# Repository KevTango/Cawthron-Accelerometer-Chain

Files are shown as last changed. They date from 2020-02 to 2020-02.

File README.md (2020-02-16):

# Cawthron Accelerometer Chain

## Author: Kevin Tang

### I wrote this code for Cawthron Institute during my internship, it is to measure the acceleration at 10 different points of the mussel farm rope and to log the data on a single SD card.

The file has three folders: 

* `receiver` for the receiver component measuring the acceleration and the temperature
* `datalogger` for requesting the data from the receiver and to log them on the SD card
* `PCB` containing the PCB files

## Code Setup

* `git clone` or download the code as a zip file

* Download uPycraft IDE or simply use a text editor such as Notepad++

* Copy respective files (main.py + boot.py + libraries) to SD card

**NOTE: If the SD card is larger than 32GB, use GUIFormat to format SD card to FAT32**

### Datalogger

1. Choose datalogging mode in `MODE` to `MODE = DATA_RATE_1HZ` for 1 Hz or `MODE = DATA_RATE_2HZ` for 2 Hz

2. To set up RTC, uncomment section under date initialisation and follow formatting

3. Run the code to save the time

4. Comment out the RTC code section as before to stop it from re-initialising the time each time

5. Rerun the code

* The red LED will light up to signify receiver 0 and/or 1 information has been received

* The green LED will light up to signify receiver 2 and/or 3 and/or 4 information has been received

* The yellow LED will light up to signify receiver 5 and/or 6 and/or 7 information has been received

* The blue LED will light up to signify receiver 8 and/or 9 information has been received

### Receiver

1. Configure ID from 0-9 under `ID = _` **MAKE SURE EACH ID NUMBER IS DIFFERENT**

2. To set up RTC, uncomment section under date initialisation and follow formatting

3. Run the code to save the time

4. Comment out the RTC code section as before to stop it from re-initialising the time each time

5. Rerun the code

* The Green LED will flash to signify the receiver has transmitted to the datalogger 

## PCB

Components needed and links for 1 datalogger and 10 receivers:

* [11 x Pyboard](https://www.digikey.co.nz/products/en?mpart=DEV-14412&v=1568)

* [11 x 1N4148](https://nz.element14.com/diodes-inc/1n4148w-7-f/diode-switch-300ma-100v-sod123/dp/1776392?st=1N4148W-7-F)

* [11 x 47uF Electrolytic Capacitor](https://nz.element14.com/panasonic/eee1ca470sp/ae-capacitor-case-radial-can-smd/dp/9696946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)

* [11 x 100nF Capacitor](https://nz.element14.com/avx/08055c104jat2a/cap-0-1-f-50v-5-x7r-0805/dp/1740673?st=100nF%200805)

* [11 x DS3231M](https://www.digikey.co.nz/product-detail/en/maxim-integrated/DS3231MPMB1/DS3231MPMB1-ND/3661364)

* [11 x CR1025 Batteries](https://www.mrpositive.co.nz/panasonic-cr1025-3v-lithium-button-cell-battery)

* [11 x TTL to RS485 Converter](https://www.aliexpress.com/item/32668863095.html)

* [10 x LIS3DH](https://www.adafruit.com/product/2809)

* [10 x TMP36](https://www.digikey.co.nz/product-detail/en/analog-devices-inc/TMP36GT9Z/TMP36GT9Z-ND/820404)

* M3 Standoffs (Optional)

Wiring diagram is provided in the PCB folder (datalogger_schematic.PNG and receiver_schematic.PNG)

Make sure the terminal A connect with other terminal A and same for terminal B

## Ordering PCBs 

I have provided the zip files containing gerber files and NC drill files in the PCB folder (Datalogger_v3.zip and Receiver_v3.zip)
[JLCPCB](https://jlcpcb.com/) is recommended

Datalogger board size: 74mm x 73mm

Receiver board size: 74mm x 70mm

## Troubleshooting

* Sometimes the compiler will append code at the bottom of original code, make sure to delete it

* If all the LEDs are flashing in order (e.g. board is corrupted), hold the USR button then the RST button.
Let go of the USR button and let go of the RST button once the yellow+green LEDs light up to reset board to factory settings.
Recopy code to SD card

* If there are errors in the code, make sure to copy the whole code, 
press Ctrl+E to enter copy paste mode in the REPL/console, paste the code then press Ctrl+D to run the code and view the error

* The csv file cannot be viewed while the SD card is plugged into the Pyboard. A SD card reader is required to view the csv file

* The watchdog timer has been disabled if the pyboard has been powered by a USB to ensure ease of debugging.
Make sure to power the Pyboard with a battery if in use.
Otherwise, enable the watchdog timers

**If there are any issues with the code/components email me or open up an issue on GitHub**

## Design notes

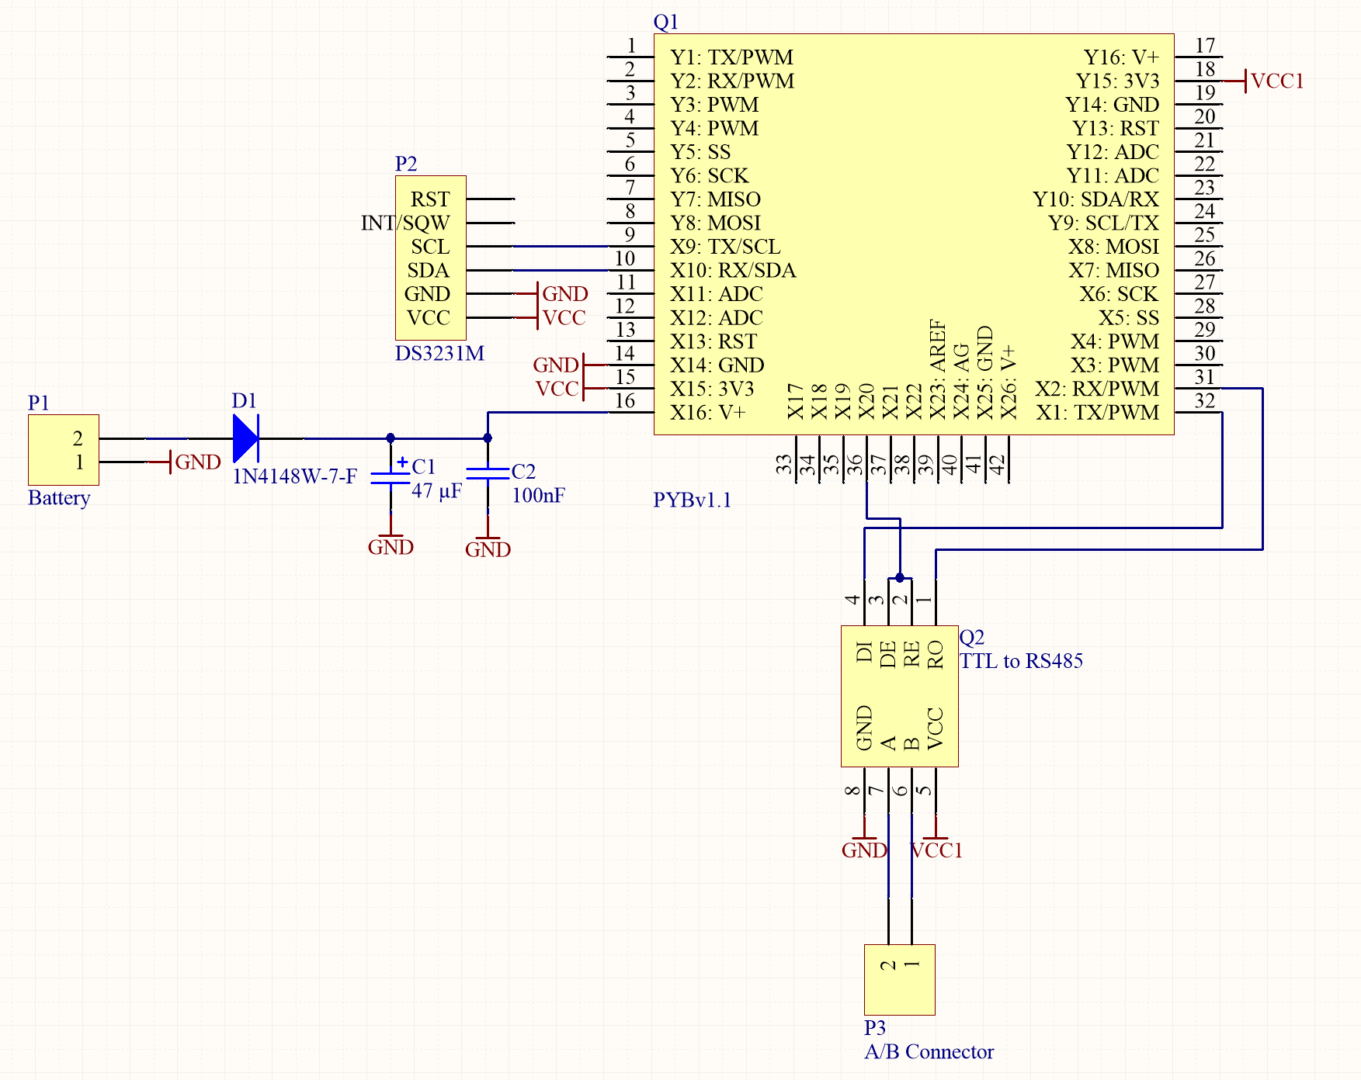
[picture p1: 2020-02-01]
PCB/Datalogger/datalogger_schematic.PNG

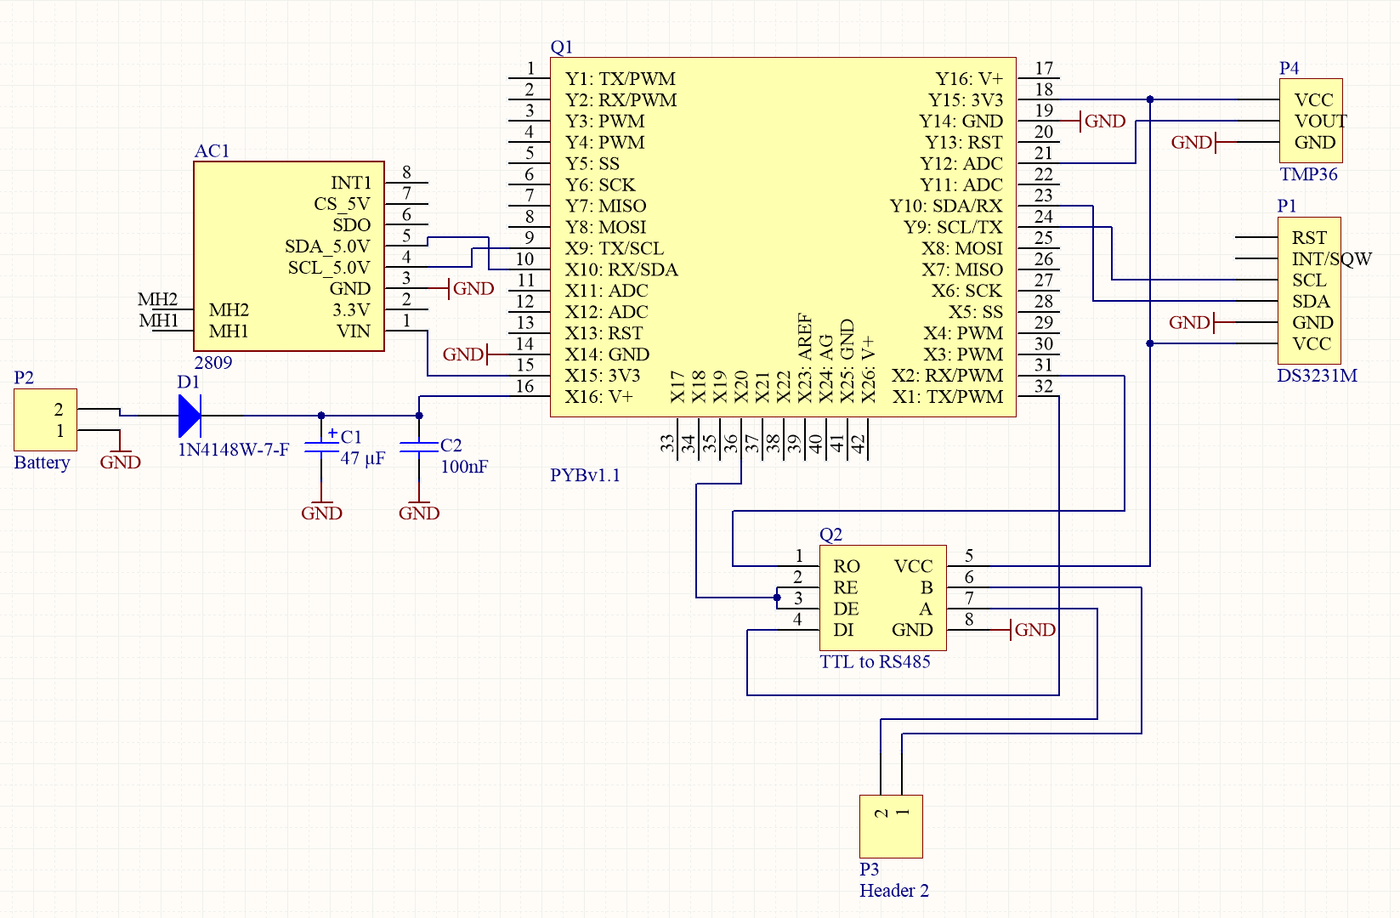
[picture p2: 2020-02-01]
PCB/Receiver/receiver_schematic.PNG

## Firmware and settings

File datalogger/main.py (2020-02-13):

# Datalogger code for Cawthron Institute's mussel farm accelerometer chain
# Author: Kevin Tang

"""
DEFAULT SETTINGS

MODE = DATA_RATE_1HZ
BAUD RATE: 9600
UART DATA FRAME: bits=8, parity=None, stop=1, timeout=1000
WDT TIMEOUT: 3000ms
1 HZ SLEEP: 30s
2 HZ SLEEP: 10s
"""

from machine import Pin, I2C, SPI, UART, WDT
from ds3231_port import DS3231
from pyb import RTC

import utime
import time
import sys
import os

# Timeout values
global SLEEP_1HZ
global SLEEP_2HZ

SLEEP_1HZ = 30
SLEEP_2HZ = 10

# Modes
global DATA_RATE_1HZ
global DATA_RATE_2HZ
global MODE

DATA_RATE_1HZ = 'one'
DATA_RATE_2HZ = 'two'

MODE = DATA_RATE_1HZ # Choose modes here (DATA_RATE_1HZ or DATA_RATE_2HZ)

# Enable Watchdog timer when batteries are plugged in.
global TIMEOUT_VALUE
TIMEOUT_VALUE = 3000

if pyb.Pin.board.USB_VBUS.value() == 0:
  wdt = WDT(timeout = TIMEOUT_VALUE) # enable watchdog timer

if sys.platform == 'pyboard':
  # Pin connections
  tx_enable = Pin('X20', mode=Pin.OUT)
  
  # RTC initialisation
  i2c = I2C(1) # Pins X9 and X10
  ds3231 = DS3231(i2c)
  
  # UART initialisation
  uart = UART(4, 115200) # Pins X1 and X2
  uart.init(115200, bits=8, parity=None, stop=1, timeout=1000) # Blocking UART of 1 second
  
else: 
  print('Incompatible system detected, please connect a pyboard')
  
# Date initialisation
rtc = RTC()
timeCheck = ds3231.get_time() # Gets current time

rtc.datetime((timeCheck[0], timeCheck[1], timeCheck[2], timeCheck[6], timeCheck[3], timeCheck[4], timeCheck[5], 0)) # Syncs RTC clock to local time

"""
# Sets up RTC, uncomment to manually set the clock (NOTE: DAY OF WEEK AND TIME ZONE IS NOT WORKING)
rtc.datetime((2020, 2, 11, 2, 16, 7, 40, 0))  # Comment out if already programmed
ds3231.save_time()

# RTC Format: YY, MM, DD, Day of week (Mon = 1), hh, mm, ss, time zone
# Example: 16/12/2019 @ Monday 16:13:00
# = rtc.datetime((2019, 12, 16, 1, 16, 13, 0, 0))
"""

# Checks to see if the csv file is empty, then writes the file if it is empty
for i in range(10):
  string = "/sd/accelerometer" + str(i) + ".csv"
  try:
    with open(string) as fileEmptyTest:
      emptyTest = fileEmptyTest.read(1)
      if not emptyTest:
        log_header = open(string, "a")
        log_header.write("ID, Date, Time, X Acceleration, Y Acceleration, Z Acceleration, Temperature \n")
        log_header.close() 
  except OSError: # File does not exist, make the files and headers
    log_header = open(string, "a")
    log_header.write("ID, Date, Time, X Acceleration, Y Acceleration, Z Acceleration, Temperature \n")
    log_header.close() 

# Retrieves date
def getDate():
  return str(rtc.datetime()[2]) + '/' + str(rtc.datetime()[1]) + '/' + str(rtc.datetime()[0])

# Retrieves time
def getTime():
  return str(rtc.datetime()[4]) + ':' + str(rtc.datetime()[5]) + ':' + str(rtc.datetime()[6])

# Sleep timer
def rest():
  if MODE == DATA_RATE_1HZ:
    for i in range(SLEEP_1HZ - 1):
      if(pyb.Pin.board.USB_VBUS.value() == 1):
        time.sleep(1)
      else:
        wdt.feed()
        rtc.wakeup(1000)
        pyb.stop()
        rtc.wakeup(None)
  else:
    for i in range(SLEEP_2HZ - 1):
      wdt.feed()
      if(pyb.Pin.board.USB_VBUS.value() == 1):
        time.sleep(1)
      else:
        wdt.feed()
        rtc.wakeup(1000)
        pyb.stop()
        rtc.wakeup(None)
  
# Reading UART value and converting to string
def uartProcess():
  test = uart.read()
  dataString = str(test)[2:-4]
  dataString = dataString.split('...')
  splitString = [i.split(',') for i in dataString]
  return splitString

# Sends mode information to receiver
def modeSelection():
  if MODE == DATA_RATE_1HZ:
    uart.write("uno")
  else:
    uart.write("dos")

# Remove WDT when USB is plugged in
def wdtCheck():
  if(pyb.Pin.board.USB_VBUS.value() == 0):
    wdt.feed()
   
# Checks if the last character is a digit and force reset if it isn't (garbage value check)
global lastChar

def charCheck():
  try:
    testing = [i for i in lastChar if i.isdigit()]
    if testing == []:
      print("Non digit detected. Forcing reset")
      wdt = WDT(timeout = 1) # Force watchdog timer
  except:
    print('Exception Error. Forcing reset')
    wdt = WDT(timeout = 1) # Force watchdog timer
  
# Resets receiver data buffers and respective sleep values based on mode selection on first start
tx_enable.value(1)
uart.write(MODE)
tx_enable.value(0)

while True:
  wdtCheck()
  print(getDate()) # Date
  print(getTime()) # Time
  
  # Print mode
  if MODE == DATA_RATE_1HZ:
    print("Mode: 1 Hz")
  else:
    print("Mode: 2 Hz")
  
  tx_enable.value(1)
  modeSelection()
  uart.write('0')
  tx_enable.value(0)
  splitString = uartProcess()
  if(splitString[0][0] == '0'):
    log_header0 = open("/sd/accelerometer0.csv", "a")
    for i in range(len(splitString)):
      log_header0.write(splitString[i][0] + ", " + splitString[i][1] + ", " + splitString[i][2] + ", " + splitString[i][3] + ", " \
      + splitString[i][4] + ", " + splitString[i][5] + ", " + splitString[i][6] + " \n")
    log_header0.close()
    print("Receiver 0 logged")
    pyb.LED(1).on()
    lastTemp = splitString[-1][-1]
    lastChar = list(lastTemp[-1])
    charCheck()
  
  wdtCheck()
  tx_enable.value(1)
  modeSelection()
  uart.write('1')
  tx_enable.value(0)
  splitString = uartProcess()
  if(splitString[0][0] == '1'):
    log_header1 = open("/sd/accelerometer1.csv", "a")
    for i in range(len(splitString)):
      log_header1.write(splitString[i][0] + ", " + splitString[i][1] + ", " + splitString[i][2] + ", " + splitString[i][3] + ", " \
      + splitString[i][4] + ", " + splitString[i][5] + ", " + splitString[i][6] + " \n")
    log_header1.close()
    print("Receiver 1 logged")
    pyb.LED(1).on()
    lastTemp = splitString[-1][-1]
    lastChar = list(lastTemp[-1])
    charCheck()
  
  wdtCheck()
  tx_enable.value(1)
  modeSelection()
  uart.write('2')
  tx_enable.value(0)
  splitString = uartProcess()
  if(splitString[0][0] == '2'):
    log_header2 = open("/sd/accelerometer2.csv", "a")
    for i in range(len(splitString)):
      log_header2.write(splitString[i][0] + ", " + splitString[i][1] + ", " + splitString[i][2] + ", " + splitString[i][3] + ", " \
      + splitString[i][4] + ", " + splitString[i][5] + ", " + splitString[i][6] + " \n")
    log_header2.close()
    print("Receiver 2 logged")
    pyb.LED(2).on()
    lastTemp = splitString[-1][-1]
    lastChar = list(lastTemp[-1])
    charCheck()
   
  wdtCheck() 
  tx_enable.value(1)
  modeSelection()
  uart.write('3')
  tx_enable.value(0)
  splitString = uartProcess()
  if(splitString[0][0] == '3'):
    log_header3 = open("/sd/accelerometer3.csv", "a")
    for i in range(len(splitString)):
      log_header3.write(splitString[i][0] + ", " + splitString[i][1] + ", " + splitString[i][2] + ", " + splitString[i][3] + ", " \
      + splitString[i][4] + ", " + splitString[i][5] + ", " + splitString[i][6] + " \n")
    log_header3.close()
    print("Receiver 3 logged")
    pyb.LED(2).on()
    lastTemp = splitString[-1][-1]
    lastChar = list(lastTemp[-1])
    charCheck()
   
  wdtCheck() 
  tx_enable.value(1)
  modeSelection()
  uart.write('4')
  tx_enable.value(0)
  splitString = uartProcess()
  if(splitString[0][0] == '4'):
    log_header4 = open("/sd/accelerometer4.csv", "a")
    for i in range(len(splitString)):
      log_header4.write(splitString[i][0] + ", " + splitString[i][1] + ", " + splitString[i][2] + ", " + splitString[i][3] + ", " \
      + splitString[i][4] + ", " + splitString[i][5] + ", " + splitString[i][6] + " \n")
    log_header4.close()
    print("Receiver 4 logged")
    pyb.LED(2).on()
    lastTemp = splitString[-1][-1]
    lastChar = list(lastTemp[-1])
    charCheck()
    
  wdtCheck()
  tx_enable.value(1)
  modeSelection()
  uart.write('5')
  tx_enable.value(0)
  splitString = uartProcess()
  if(splitString[0][0] == '5'):
    log_header5 = open("/sd/accelerometer5.csv", "a")
    for i in range(len(splitString)):
      log_header5.write(splitString[i][0] + ", " + splitString[i][1] + ", " + splitString[i][2] + ", " + splitString[i][3] + ", " \
      + splitString[i][4] + ", " + splitString[i][5] + ", " + splitString[i][6] + " \n")
    log_header5.close()
    print("Receiver 5 logged")
    pyb.LED(3).on()
    lastTemp = splitString[-1][-1]
    lastChar = list(lastTemp[-1])
    charCheck()
  
  wdtCheck()
  tx_enable.value(1)
  modeSelection()
  uart.write('6')
  tx_enable.value(0)
  splitString = uartProcess()
  if(splitString[0][0] == '6'):
    log_header6 = open("/sd/accelerometer6.csv", "a")
    for i in range(len(splitString)):
      log_header6.write(splitString[i][0] + ", " + splitString[i][1] + ", " + splitString[i][2] + ", " + splitString[i][3] + ", " \
      + splitString[i][4] + ", " + splitString[i][5] + ", " + splitString[i][6] + " \n")
    log_header6.close()
    print("Receiver 6 logged")
    pyb.LED(3).on()
    lastTemp = splitString[-1][-1]
    lastChar = list(lastTemp[-1])
    charCheck()
   
  wdtCheck() 
  tx_enable.value(1)
  modeSelection()
  uart.write('7')
  tx_enable.value(0)
  splitString = uartProcess()
  if(splitString[0][0] == '7'):
    log_header7 = open("/sd/accelerometer7.csv", "a")
    for i in range(len(splitString)):
      log_header7.write(splitString[i][0] + ", " + splitString[i][1] + ", " + splitString[i][2] + ", " + splitString[i][3] + ", " \
      + splitString[i][4] + ", " + splitString[i][5] + ", " + splitString[i][6] + " \n")
    log_header7.close()
    print("Receiver 7 logged")
    pyb.LED(3).on()
    lastTemp = splitString[-1][-1]
    lastChar = list(lastTemp[-1])
    charCheck()
  
  wdtCheck()
  tx_enable.value(1)
  modeSelection()
  uart.write('8')
  tx_enable.value(0)
  splitString = uartProcess()
  if(splitString[0][0] == '8'):
    log_header8 = open("/sd/accelerometer8.csv", "a")
    for i in range(len(splitString)):
      log_header8.write(splitString[i][0] + ", " + splitString[i][1] + ", " + splitString[i][2] + ", " + splitString[i][3] + ", " \
      + splitString[i][4] + ", " + splitString[i][5] + ", " + splitString[i][6] + " \n")
    log_header8.close()
    print("Receiver 8 logged")
    pyb.LED(4).on()
    lastTemp = splitString[-1][-1]
    lastChar = list(lastTemp[-1])
    charCheck()
  
  wdtCheck()
  tx_enable.value(1)
  modeSelection()
  uart.write('9')
  tx_enable.value(0)
  splitString = uartProcess()
  if(splitString[0][0] == '9'):
    log_header9 = open("/sd/accelerometer9.csv", "a")
    for i in range(len(splitString)):
      log_header9.write(splitString[i][0] + ", " + splitString[i][1] + ", " + splitString[i][2] + ", " + splitString[i][3] + ", " \
      + splitString[i][4] + ", " + splitString[i][5] + ", " + splitString[i][6] + " \n")
    log_header9.close()
    print("Receiver 9 logged")
    pyb.LED(4).on()
    lastTemp = splitString[-1][-1]
    lastChar = list(lastTemp[-1])
    charCheck()
  
  print()
  pyb.LED(1).off()
  pyb.LED(2).off()
  pyb.LED(3).off()
  pyb.LED(4).off()
  
  wdtCheck()
  rest()

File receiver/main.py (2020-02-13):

# Receiver code for Cawthron Institute's mussel farm accelerometer chain
# Author: Kevin Tang

"""
DEFAULT VALUES

MODE: 1 HZ
BAUD RATE: 9600
DATA FRAME: bits=8, parity=None, stop=1, timeout=0
WDT TIMEOUT: 3000ms
ACCELEROMETER RANGE: 2G
ACCELEROMETER FREQUENCY: 10HZ
"""

from machine import I2C, Pin, SPI, UART, WDT
from lis3dh import LIS3DH, LIS3DH_I2C, RANGE_2_G, DATARATE_10_HZ, STANDARD_GRAVITY
from pyb import ADC, RTC
from ds3231_port import DS3231
import time
import os
import sys
import math

global ID
global timer
ID = 0 # Receiver ID (0-9). MAKE SURE TO CHANGE
timer = 1 # By default, sleep value is set to 1s (1 Hz mode)

# Enable Watchdog timer if using battery
global TIMEOUT_VALUE
TIMEOUT_VALUE = 3000

if pyb.Pin.board.USB_VBUS.value() == 0:
  wdt = WDT(timeout = TIMEOUT_VALUE) # enable with a timeout of 3 seconds

if sys.platform == 'pyboard':
  # Initialising pins
  thermistor = pyb.ADC('Y12')
  tx_enable = Pin('X20', Pin.OUT)
  
  # Initialising I2C
  i2c = I2C(1) # Pins X9 and X10
  rtc_i2c = I2C(2) # Pins Y9 and Y10
  ds3231 = DS3231(rtc_i2c)
  accelerometer = LIS3DH_I2C(i2c, int1=None)
  
  # Initialising UART
  uart = UART(4, 115200) # Pins X1 and X2
  uart.init(115200, bits=8, parity=None, stop=1, timeout=0) # Non-blocking UART
else:
  print('Incompatible board detected, please connect pyboard')

# Date initialisation
rtc = RTC()
timeCheck = ds3231.get_time() # Gets current time

rtc.datetime((timeCheck[0], timeCheck[1], timeCheck[2], timeCheck[6], timeCheck[3], timeCheck[4], timeCheck[5], 0)) # Syncs RTC clock to local time

"""
# Sets up RTC, uncomment to manually set the clock (NOTE: DAY OF WEEK AND TIME ZONE IS NOT WORKING)

rtc.datetime((2020, 2, 11, 2, 15, 48, 50, 0))  # Comment out if already programmed
ds3231.save_time()

# RTC Format: YY, MM, DD, Day of week (Mon = 1), hh, mm, ss, time zone
# Example: 16/12/2019 @ Monday 16:13:00
# = rtc.datetime((2019, 12, 16, 1, 16, 13, 0, 0))
"""

# Function to create and write headers for the accelerometer csv
def writeHeader():
  print('writing header')
  log_header = open("/sd/accelerometer.csv", "a")
  log_header.write("ID, Date, Time, X Acceleration, Y Acceleration, Z Acceleration, Temperature \n")
  log_header.close()

# Retrieves date
def getDate():
  return str(rtc.datetime()[2]) + '/' + str(rtc.datetime()[1]) + '/' + str(rtc.datetime()[0])

# Retrieves time
def getTime():
  return str(rtc.datetime()[4]) + ':' + str(rtc.datetime()[5]) + ':' + str(rtc.datetime()[6])
 
# Low power delay
def rest():
  if pyb.Pin.board.USB_VBUS.value() == 1:
    time.sleep(timer)
  else:
    rtc.wakeup(timer*1000)
    pyb.stop()
    rtc.wakeup(None)
  
LIS3DH.range = RANGE_2_G # Setting range to 2G (increasing the value to 4G will double the g force which is inaccurate)
LIS3DH.datarate = DATARATE_10_HZ # Setting data rate to 10 Hz

dataBuffer = str() # Initialising empty string

# Checks to see if the csv file is empty, then writes the file if it is empty
try:
  with open("/sd/accelerometer.csv") as fileEmptyTest:
    emptyTest = fileEmptyTest.read(1)
    if not emptyTest:
      writeHeader()
    else:
      print('csv file is not empty')
except OSError: # File does not exist, make the files and headers
  writeHeader()
  
while True:
  if pyb.Pin.board.USB_VBUS.value() == 0:
    wdt.feed() # Kicks watchdog timer
  tx_enable.value(0)
  read = uart.read()
  idCheck = str(read)[-2]
  modeCheck = str(read)[2:5]
  
  print(getDate()) # Date
  print(getTime()) # Time
  print("Receiver ID: " + str(ID)) # Receiver ID
  
  if timer == 1:
    print("MODE: 1 HZ")
  else:
    print("MODE: 2 HZ")
  
  # Print X,Y,Z acceleration values in g forces
  x, y, z = [value for value in accelerometer.acceleration]
  
  x = x / STANDARD_GRAVITY
  y = y / STANDARD_GRAVITY
  z = z / STANDARD_GRAVITY
  
  xRounded = round(x, 2)
  yRounded = round(y, 2)
  zRounded = round(z, 2)
  print("Acceleration: " + str(xRounded) + ", " + str(yRounded) + ", " + str(zRounded))
  
  # Thermistor readings
  thermistorTest = thermistor.read() / 4095
  thermistorTest *= 100
  thermistorRounded = round(thermistorTest, 2)
  print("Temperature: " + str(thermistorRounded))
  
  # Write data to csv file
  log_header = open("/sd/accelerometer.csv", "a")
  log_header.write(str(ID) + ", " + getDate() + ", " + getTime() + ", " + str(xRounded) + ", " + str(yRounded) + ", " + \
  str(zRounded) + ", " + str(thermistorRounded) + " \n")
  log_header.close()
  
  dataString = str(ID) + ',' + getDate() + ',' + getTime() + ',' + str(xRounded) + ',' + str(yRounded) + ',' + str(zRounded) + ',' + str(thermistorRounded) + "..."
  dataBuffer += dataString
  
  # Adjusts mode based on datalogger and clears buffer to prevent overflow
  # Removed buffer reset, can enable later
  if modeCheck == 'one':
    #dataBuffer = str()
    timer = 1
    #print("Buffer cleared. Set to 1 Hz")
  elif modeCheck == 'two':
    #dataBuffer = str()
    timer = 0.5
    #print("Buffer cleared. Set to 2 Hz")
  elif modeCheck == 'uno':
    timer = 1
  elif modeCheck == 'dos':
    timer = 0.5
  
  if idCheck == str(ID):
    tx_enable.value(1)
    print(uart.write(str(dataBuffer)))
    pyb.LED(2).on() # Debug LED
    tx_enable.value(0)
    dataBuffer = str() # Clear buffer once it sends the data values
    idCheck = str(99) # Arbitary reset number
    print('transmit')
    
  print()
  pyb.LED(2).off()
  
  rest()

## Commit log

2020-01-08 fixed serial.py uart issue
    [main.py]
2020-01-09 added flow in datalogger uart
2020-01-12 added low power delay and 10 accelerometer csv files
    [accelerometer1.csv, accelerometer10.csv, accelerometer2.csv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]
2020-01-12 rounded acceleration and temperature to 2 dp
2020-01-12 added green debug led
2020-01-13 receiver uart working
2020-01-15 changed esp32 receiver to pyboard
2020-01-16 basic receiver uart packet done
2020-01-16 basic datalogger functionality done
    [accelerometer1.csv]
2020-01-16 removed redundant datalogger code
    [accelerometer1.csv]
2020-01-16 optimised datalogger code
    [accelerometer1.csv]
2020-01-16 removed additional code created by upycraft
    [accelerometer1.csv]
2020-01-16 finalised datalogger with debug messages
    [accelerometer1.csv]
2020-01-19 added receiver rtc and fixed deleted code
    [ds3231_port.py, main.py]
2020-01-20 changed datalogger port to better fit pcb
2020-01-22 added wdt to datalogger
    [accelerometer1.csv, accelerometer10.csv, accelerometer2.csv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]
2020-01-23 tentative datalogger uart change test
2020-01-23 debugged uart error
2020-01-23 changed baud rate to 115200 and added delay to save battery
2020-01-24 removed print statements
2020-01-27 added functionalities and fixed bugs
    [main.py]
2020-01-28 added power saving mode
2020-02-01 added pcb files
    [Datalogger.PrjPcb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]
2020-02-03 pcb readme file done
2020-02-03 added pcb ordering
2020-02-11 fixed print error
2020-02-11 adjusted sleep timer
2020-02-13 updated 1hz default sleep value
2020-02-16 updated pcbs
    [Datalogger.PrjPcb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]
